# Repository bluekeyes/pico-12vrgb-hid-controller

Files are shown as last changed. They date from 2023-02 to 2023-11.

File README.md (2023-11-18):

# pico-12vrgb-hid-controller

A 4-channel 12V-G-R-B controller for RGB fans and LED strips using the Raspberry
Pi Pico and controlled via USB HID. Designed to be installed inside a PC case as
an alternative or addition to motherboard headers.

It implements the "Lighting and Illumination" (`0x59`) HID usage page, making
it fully compatible with the [Dynamic Lighting][] feature in Windows 11.

It also implements the "Sensors" (`0x20`) HID usage page (for a temperature
sensor) and a vendor (`0xFF00`) HID usage page for custom controls.

Note this does *not* support 3-pin addressable RGB LEDs, but uses the
semi-standard 4-pin 12V-G-R-B connector, where all devices connected to a
channel show the same color.

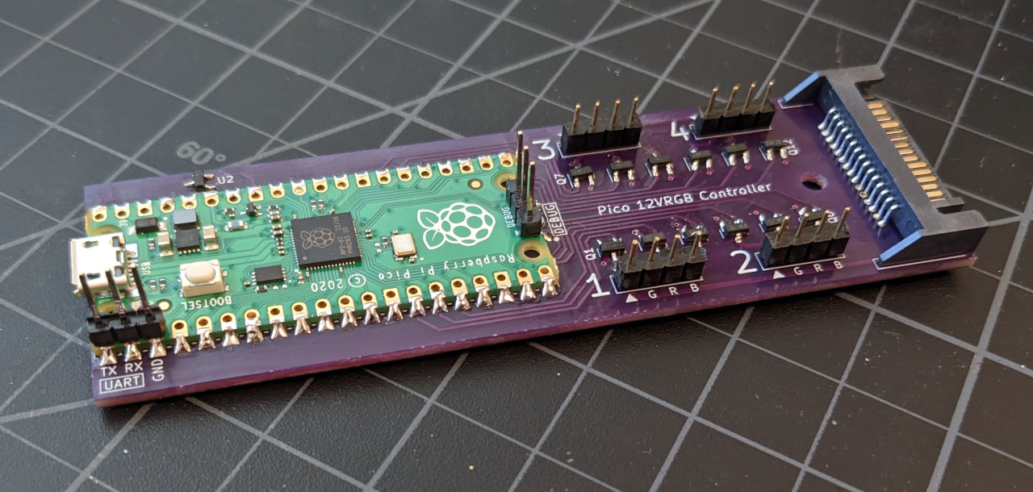
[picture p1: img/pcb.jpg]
The assembled pico-12vrgb-hid-controller PCB


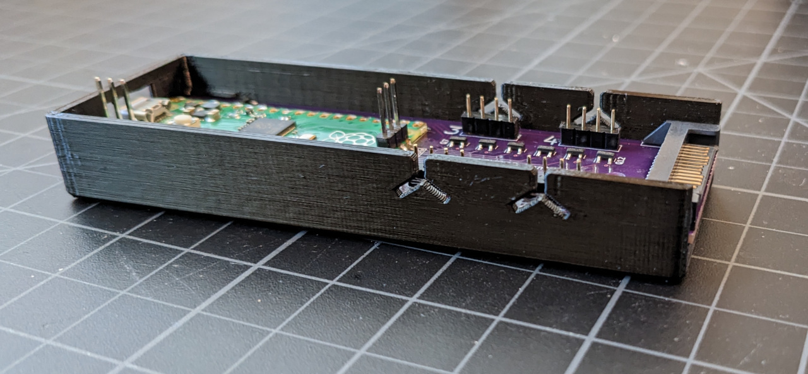
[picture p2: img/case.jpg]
The assembled PCB installed in the 3D-printed case


[Dynamic Lighting]: https://support.microsoft.com/en-us/windows/control-your-dynamic-lighting-devices-in-windows-8e8f22e3-e820-476c-8f9d-9ffc7b6ffcd2

## Animations

When running in autonomous mode, the controller implements configurable
animations. Use the CLI to set the parameters or save an animation as the
default for a channel.

### Breathe

Fades a single color on and off. The fade on time, on time, fade off time, and
off time are all configurable.

https://user-images.githubusercontent.com/1745813/233868169-5f5d1403-0b08-4b99-b51f-30fe5f666057.mp4

### Fade

Fades between up to 8 different colors. The fade time and hold time are
configurable.

https://user-images.githubusercontent.com/1745813/233868393-662b7a13-106e-483d-9052-4a47977f7780.mp4

## Project Structure

This project is split into three parts:

* `hw/` contains schematics and PCB files (KiCAD)
* `fw/` contains device firmware (C)
* `cli/` contains the command-line control program (Rust)

See each directory for more details.

## Limitations

The hardware is only tested on Windows 11, using both the Dynamic Lighting
feature and the included CLI. The CLI does not support other platforms yet. 

## License

MIT

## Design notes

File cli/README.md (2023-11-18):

# pico-12vrgb-ctrl

A program to control the USB device from the command line. See the help output
for details on the supported commands:

```
Usage: pico-12vrgb-ctrl.exe [OPTIONS] <COMMAND>

Commands:
  lamp-array       Control lights directly
  set-animation    Manage built-in animations
  reset            Reset the controller hardware
  get-temperature  Read the internal temperature sensor
  help             Print this message or the help of the given subcommand(s)

Options:
      --vendor-id <ID>   Override the USB vendor ID for the device
      --product-id <ID>  Override the USB product ID for the device
  -h, --help             Print help
  -V, --version          Print version
```

## Platform Support

The CLI is structured to support multiple platforms, but currently only
implements a Windows backend. Other backends might be added if there's a need
for them.

### Windows

On Windows, the CLI uses WinRT and Win32 APIs (via the [`windows`
crate][windows-rs]) to interact with the device. Partly due to API limitations
and partly for simplicity, the CLI sends reports in the exact binary format
expected by the device. This means it only works with the firmware from this
repository and that the CLI version and the firmware version must match.

The main reason to use Windows APIs directly instead of an abstraction library
like `hidapi` is that sensor devices are only accessible via the Win32 Sensors
API and are hidden from the normal HID APIs.

The CLI uses exact binary report formats because the
`Windows.Devices.HumanInterfaceDevice` API provides no way I could find to set
repeated report items by HID usage. I think this limitation does not exist in
the lower-level Win32 HID API, but the WinRT API is easier to use and has nicer
Rust bindings.

Currently, all parts of the `lamp-array` subcommand exit immediately. Similar
to sensors, once a HID device is detected as as a more specific subclass,
Windows hides it from the generic HID APIs. The `Windows.Devices.Lights` API
does not map one-to-one with the underlying HID messages and so isn't a direct
replacement. It also has limitations on when apps can use this API to control
the device (e.g. they must be in the foreground.)

The [Dynamic Lighting][] UI is a reasonable substitute for most of the
`lamp-array` subcommmands.

[windows-rs]: https://crates.io/crates/windows
[Dynamic Lighting]: https://support.microsoft.com/en-us/windows/control-your-dynamic-lighting-devices-in-windows-8e8f22e3-e820-476c-8f9d-9ffc7b6ffcd2

## Development

This is a standard Rust project that builds with `cargo`. There are no
requirements apart from a working Rust installation.

From this directory:

```
# compile the binary, output is in the `target/debug` directory
$ cargo build

# complie and run the binary, with subcommands and flags after the "--"
$ cargo run -- set-animation --help
```

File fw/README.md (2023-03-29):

# pico-12vrgb-controller

This directory contains a Pico SDK project for the controller firmware. The
Raspberry Pi Pico SDK and `cmake` are required.

## Building

```
export PICO_SDK_PATH=/path/to/pico-sdk-1.5.0
mkdir build
cd build
cmake ..
make
```

Edit `src/config.h` before building to modify device configuration.

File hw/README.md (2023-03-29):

# Hardware

This directory contains design files for the controller hardware:

* `pcb` - a KiCAD 7.x project with the schematic and PCB design
* `case` - OpenSCAD and STL files for a simple 3D printed case for the PCB

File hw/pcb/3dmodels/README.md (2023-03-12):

# 3D Models

This directory contains 3D models associated with KiCad footprints in this project:

* `moddiy_15pin_sata_right_angle_header.step` - created from datasheet and physical measurments
* `raspberry_pi_pico_r3.step` - original file available at https://www.raspberrypi.com/documentation/microcontrollers/raspberry-pi-pico.html, modified to have colors

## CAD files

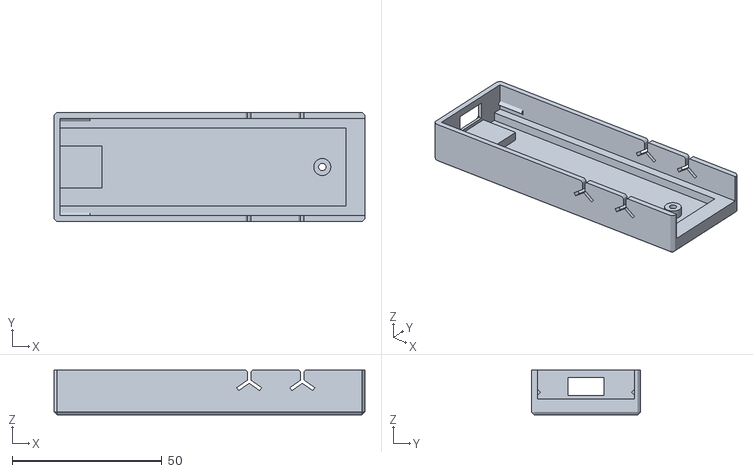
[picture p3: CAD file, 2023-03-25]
hw/case/case.stl
104.0 x 36.5 x 15.0

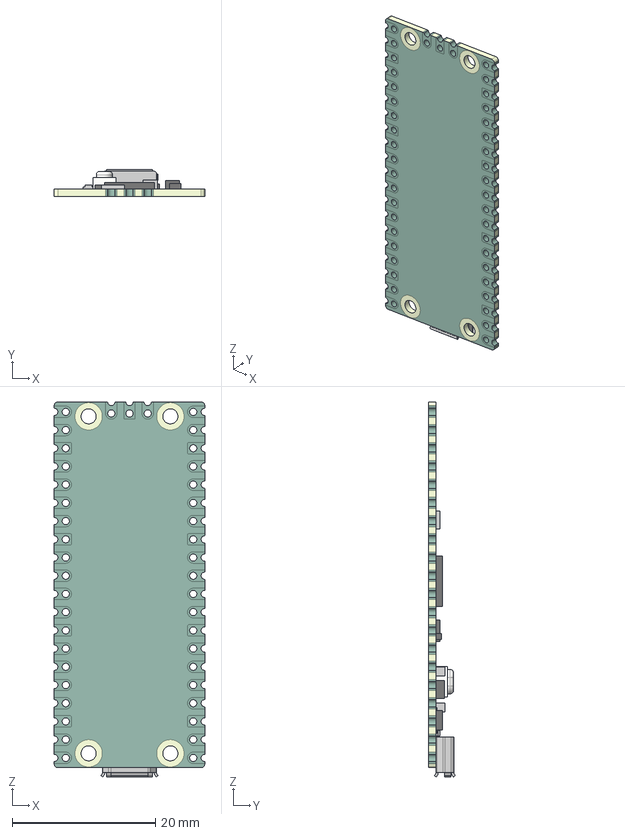
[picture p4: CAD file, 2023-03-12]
hw/pcb/3dmodels/raspberry_pi_pico_r3.step
21.0 x 3.73 x 52.3 mm
PICO_REF_BOARD.STEP
PICO_REF_USB.STEP
PICO_REF_SWITCH.STEP
PICO_REF_MICROCONTROLLER.STEP
PICO_REF_LED.STEP
PICO_REF_ONSEMI.STEP
PICO_BOURNS.STEP
PICO_MURATA.STEP x 2
PICO_RICHTEK.STEP
PICO_DIODES.STEP
PICO_AEL.STEP
PICO_WINBOND.STEP

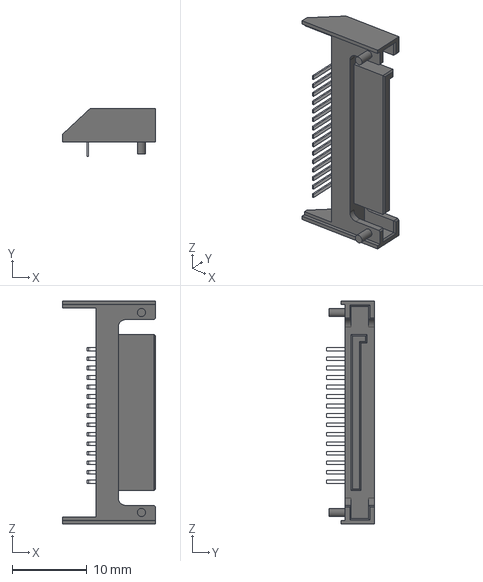
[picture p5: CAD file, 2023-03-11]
hw/pcb/3dmodels/moddiy_15pin_sata_right_angle_header.step
12.5 x 6.50 x 29.9 mm

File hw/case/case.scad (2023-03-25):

function in2mm(v) = 25.4*v;

$fa = 0.5;
$fs = 0.35;
eps = 1;

wall = 2;
standoff_wall = 1.6;

pcb_width = in2mm(1.25);
pcb_length = in2mm(4);
pcb_height = 1.6;

pcb_clearance = 0.4;
pin_clearance = 3;

rgb_offset_x = in2mm(0.825);
rgb_offset_y = in2mm(0.175);
rgb_spacing = in2mm(0.7);

rgb_cable_width = 5;
rgb_cable_height = 1.2;

usb_width = 12;
usb_height = 6;
usb_center_offset_z = 2.5;

case_width = 2*wall + 2*pcb_clearance + pcb_width;
case_length = wall + pcb_clearance + pcb_length;
case_floor = 2.4;
case_pcb_depth = 8;
case_height = case_floor + pin_clearance + pcb_height + case_pcb_depth;

screw_diameter = 2.5;
screw_length = 6;
screw_offset = in2mm(0.5625);

clip_size = 1;

assert(pcb_height + pin_clearance + case_floor >= screw_length, "screw is too long for the mounting hole");

module mirror_x() {
    children(); mirror([1, 0, 0]) children();
}

module mirror_y() {
    children(); mirror([0, 1, 0]) children();
}

module mirror_z() {
    children(); mirror([0, 0, 1]) children();
}

module rgb_cable_guide(h, angle=45) {
    translate([0, -eps/2, -h])
    union() {
        mirror_x()
        translate([rgb_cable_height/2, 0, 0])
        rotate([0, -angle, 0])
        translate([-rgb_cable_width, 0, 0])
        cube([rgb_cable_width, wall + eps, rgb_cable_height]);

        translate([-rgb_cable_height/2, 0, 0])
        cube([rgb_cable_height, wall + eps, h + eps]);

        mirror_x()
        translate([rgb_cable_height/2, (wall + eps)/2, h])
        rotate([180, 0, 90])
        chamfer_mask(rgb_cable_height/2, wall + eps);
    }
}

module chamfer_mask(s, length) {
    rotate([0, -90, 0])
    linear_extrude(length, center=true)
    polygon([
        [-eps, -eps], [s, -eps], [s, 0], [0, s], [-eps, s]
    ]);
}

module chamfer_outside_corner_mask(s) {
    polyhedron(
        points = [
            [0, 0, 0], [0, 0, s],
            [s, 0, s], [s, 0, 0],
            [0, s, s], [0, s, 0],
            [s, s, 0]
        ],
        faces = [
            // chamfer face
            [2, 4, 6],
            // side faces
            [2, 6, 3],
            [0, 1, 2, 3],
            [5, 4, 1, 0],
            [5, 6, 4],
            // top
            [1, 4, 2],
            // bottom
            [0, 3, 6, 5],
        ]
    );
}

module chamfer_inside_corner_mask(s) {
    polyhedron(
        points = [
            [eps, 0, 0], [0, eps, 0], [0, 0, eps],
            [0, 0, -s], [eps, 0, -s], [0, eps, -s],
            [-s, 0, 0], [-s, eps, 0], [-s, 0, eps],
            [0, -s, 0], [eps, -s, 0], [0, -s, eps],
        ],
        faces = [
            // chamfer face
            [3, 6, 9],
            // bottom side faces
            [3, 9, 10, 4],
            [10, 0, 4],
            [3, 5, 7, 6],
            [7, 5, 1],
            [1, 5, 4, 0],
            // top side faces
            [9, 6, 8, 11],
            [9, 11, 10],
            [10, 11, 2, 0],
            [0, 2, 1],
            [1, 2, 8, 7],
            [6, 7, 8],
            // top face
            [2, 11, 8],
            // bottom face
            [3, 4, 5],
        ]
    );
}

module case_shell() {
    chamfer = wall/2;

    difference() {
        // body
        translate([-case_length/2, -case_width/2, 0])
        cube([case_length, case_width, case_height]);

        // bottom length chamfers
        mirror_y()
        translate([0, -case_width/2, 0])
        chamfer_mask(chamfer, case_length);

        // bottom width chamfers
        mirror_x()
        translate([case_length/2, 0, 0])
        rotate([0, 0, 90])
        chamfer_mask(chamfer, case_width);

        // vertical corner chamfers
        mirror_x()
        mirror_y() {
            translate([-case_length/2, -case_width/2, 0]) {
                translate([0, 0, case_height/2])
                rotate([0, 90, 0])
                chamfer_mask(chamfer, case_height + eps);

                chamfer_outside_corner_mask(chamfer);
            }
        }

        // main cutout 
        translate([
            -case_length/2 + wall,
            -pcb_width/2 - pcb_clearance,
            case_floor
        ])
        cube([
            pcb_clearance + pcb_length + eps,
            2*pcb_clearance + pcb_width,
            case_height - case_floor + eps,
        ]);

        // usb cutout
        let (
            dz = case_floor + pin_clearance + pcb_height + usb_center_offset_z
        ) {
            translate([
                -(case_length + eps)/2,
                -usb_width/2,
                dz - usb_height/2,
            ])
            cube([wall + eps, usb_width, usb_height]);

            // chamfers
            translate([-case_length/2, 0, dz]) {
                mirror_z()
                translate([0, 0, usb_height/2])
                rotate([0, 0, -90])
                chamfer_mask(chamfer, usb_width);

                mirror_y()
                translate([0, -usb_width/2, 0])
                rotate([90, 0, 0])
                rotate([0, 0, -90])
                chamfer_mask(chamfer, usb_height);

                mirror_y()
                mirror_z()
                translate([0, -usb_width/2, -usb_height/2])
                rotate([0, -90, 0])
                chamfer_inside_corner_mask(chamfer);
            }
        }

        // rgb cable guides
        mirror_y() {
            for (i = [0, 1]) {
                translate([
                    case_length/2 - rgb_offset_x - i*rgb_spacing,
                    -case_width/2,
                    case_height,
                ])
                rgb_cable_guide(0.5 * case_pcb_depth, angle=35);
            }
        }
    }
}

module standoffs() {
    edge_width = in2mm(0.125);
    pico_length = 14;
    pico_width = 14;
    sata_length = in2mm(0.25);
    inner_w = pcb_width + 2*pcb_clearance;

    // edge supports
    mirror_y()
    translate([
        -case_length/2 + wall,
        (pcb_width/2 + pcb_clearance) - edge_width,
        0,
    ])
    cube([pcb_length + pcb_clearance, edge_width, pin_clearance]);

    // sata connector support
    translate([case_length/2 - sata_length, -inner_w/2, 0])
    cube([sata_length, inner_w, pin_clearance]);

    // pico support
    translate([-case_length/2 + wall, -pico_width/2, 0])
    cube([pico_length, pico_width, pin_clearance]);

    // screw standoff
    translate([case_length/2 - screw_offset, 0, 0])
    cylinder(d=screw_diameter + 2*standoff_wall, h=pin_clearance);
}

module clips(length) {
    dz = pcb_height - pcb_clearance;
    mirror_y()
    translate([
        0,
        pcb_width/2 + pcb_clearance,
        case_floor + pin_clearance + clip_size + dz,
    ])
    rotate([0, 90, 0])
    cylinder(r=clip_size, h=length, $fn=4);
}

module case() {
    difference() {
        union() {
            case_shell();
            translate([0, 0, case_floor]) standoffs();

            translate([-case_length/2 + wall, 0, 0])
            clips(10);
        }

        // screw hole
        translate([case_length/2 - screw_offset, 0, -eps/2])
        cylinder(d=screw_diameter, h=case_floor + pin_clearance + eps);
    }
}

case();

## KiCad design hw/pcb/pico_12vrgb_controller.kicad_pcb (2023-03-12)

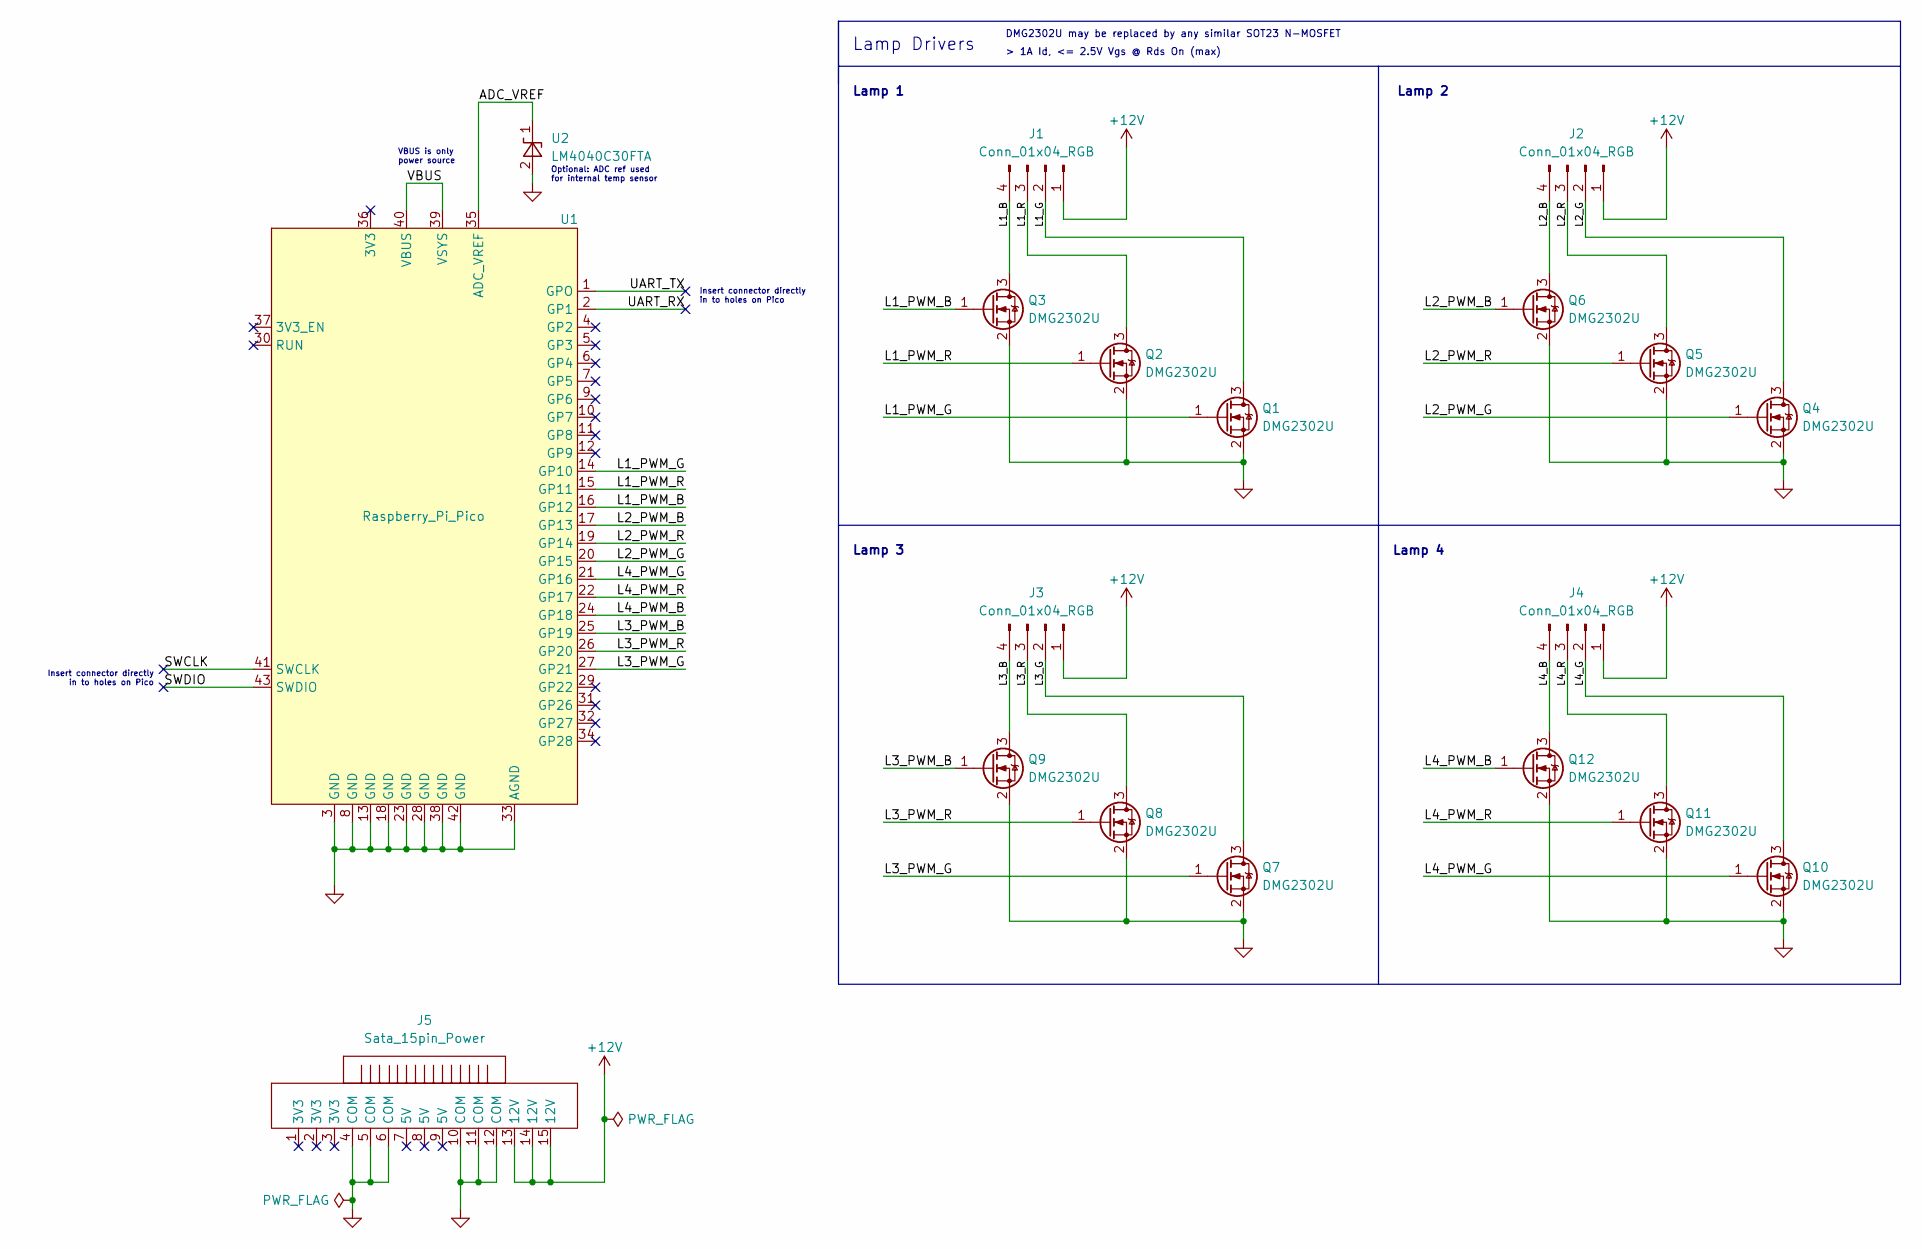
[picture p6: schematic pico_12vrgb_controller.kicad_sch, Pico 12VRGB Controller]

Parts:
J1, J2: Conn_01x04_RGB; PinHeader_12VGRB_Vertical_LeftText
J3, J4: Conn_01x04_RGB; PinHeader_12VGRB_Vertical_RightText
J5: Sata_15pin_Power; ModDIY_SATA_15pin_RightAngle_Header
Q1, Q2, Q3, Q4, Q5, Q6, Q7, Q8, Q9, Q10, Q11, Q12: DMG2302U; SOT-23
U1: Raspberry_Pi_Pico; RPi_Pico_SMD
U2: LM4040C30FTA; SOT-23

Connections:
+12V: J1.1, J2.1, J3.1, J4.1, J5.13 (12V), J5.14 (12V), J5.15 (12V)
/ADC_VREF: U1.35 (ADC_VREF), U2.1 (K)
/L1_B: J1.4, Q3.3 (D)
/L1_G: J1.2, Q1.3 (D)
/L1_PWM_B: Q3.1 (G), U1.16 (GP12)
/L1_PWM_G: Q1.1 (G), U1.14 (GP10)
/L1_PWM_R: Q2.1 (G), U1.15 (GP11)
/L1_R: J1.3, Q2.3 (D)
/L2_B: J2.4, Q6.3 (D)
/L2_G: J2.2, Q4.3 (D)
/L2_PWM_B: Q6.1 (G), U1.17 (GP13)
/L2_PWM_G: Q4.1 (G), U1.20 (GP15)
/L2_PWM_R: Q5.1 (G), U1.19 (GP14)
/L2_R: J2.3, Q5.3 (D)
/L3_B: J3.4, Q9.3 (D)
/L3_G: J3.2, Q7.3 (D)
/L3_PWM_B: Q9.1 (G), U1.25 (GP19)
/L3_PWM_G: Q7.1 (G), U1.27 (GP21)
/L3_PWM_R: Q8.1 (G), U1.26 (GP20)
/L3_R: J3.3, Q8.3 (D)
/L4_B: J4.4, Q12.3 (D)
/L4_G: J4.2, Q10.3 (D)
/L4_PWM_B: Q12.1 (G), U1.24 (GP18)
/L4_PWM_G: Q10.1 (G), U1.21 (GP16)
/L4_PWM_R: Q11.1 (G), U1.22 (GP17)
/L4_R: J4.3, Q11.3 (D)
/SWCLK: U1.41 (SWCLK)
/SWDIO: U1.43 (SWDIO)
/UART_RX: U1.2 (GP1)
/UART_TX: U1.1 (GPO)
/VBUS: U1.39 (VSYS), U1.40 (VBUS)
GND: J5.4 (COM), J5.5 (COM), J5.6 (COM), J5.10 (COM), J5.11 (COM), J5.12 (COM), Q1.2 (S), Q2.2 (S), Q3.2 (S), Q4.2 (S), Q5.2 (S), Q6.2 (S), Q7.2 (S), Q8.2 (S), Q9.2 (S), Q10.2 (S), Q11.2 (S), Q12.2 (S), U1.3 (GND), U1.8 (GND), U1.13 (GND), U1.18 (GND), U1.23 (GND), U1.28 (GND), U1.33 (AGND), U1.38 (GND), U1.42 (GND), U2.2 (A)

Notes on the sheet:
Lamp 2
Lamp Drivers
> 1A Id, <= 2.5V Vgs @ Rds On (max)
Insert connector directly in to holes on Pico
DMG2302U may be replaced by any similar SOT23 N-MOSFET
Optional: ADC ref used for internal temp sensor
Lamp 4
Lamp 1
VBUS is only power source
Lamp 3

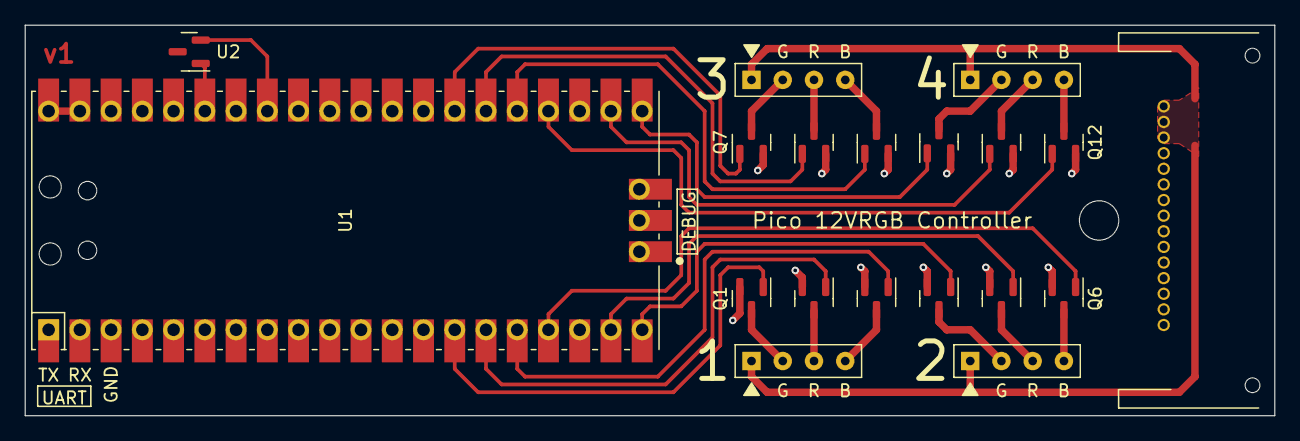
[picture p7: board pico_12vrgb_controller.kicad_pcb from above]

Board: 2 copper layers, 101.6 x 31.8 mm, 19 parts (0 on the bottom side), 28 nets.

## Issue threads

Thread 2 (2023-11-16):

Fix compatibility with Windows Dynamic Lighting

bluekeyes, 2023-11-16:
Now that Dynamic Lighting is available in Window 11, it turns out my device isn't actually compatible. As discussed a bit [in the README for the `cli` package](https://github.com/bluekeyes/pico-12vrgb-hid-controller/tree/main/cli#windows), when I tried to test this using the Windows APIs previously, I ran in to a hang that I couldn't solve. Unsurprisingly, whatever causes that problem also prevents Dynamic Lighting from working, since it presumably uses the same underlying APIs.

Since I last tried debugging this, Microsoft published https://github.com/microsoft/RP2040MacropadHidSample, which is also an RP2040-based implementation. The `LampArray` APIs correctly discover a device running this sample code without hanging, which proves that the issue is with my code and not with Windows. I now think there's something wrong with my HID descriptor that causes the Windows APIs to hang.

bluekeyes, 2023-11-17:
Updating the HID descriptor fixed the hang and the device now appears in the Dynamic Lighting settings page. Enabling and disabling autonomous mode works, but it doesn't actually respond to color changes. Still have some more debugging to do here.

Closed 2023-11-18.

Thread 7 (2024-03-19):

Find an alternate way to access HID interfaces from CLI

bluekeyes, 2024-03-19:
Once Windows detects a HID device as implementing a more specific API in the WinRT set, it seems to hide it from the generic WinRT HID API. While you can often still list the device, I couldn't actually open it or send messages.

This is mostly an issue for the `lamp-array` subcommand, which is a direct binding to the Lighting and Illuminate HID API.

I haven't tried yet, but I suspect the lower-level win32 HID API might allow access to this device, even if the higher-level APIs do not: https://learn.microsoft.com/en-us/windows/win32/api/_hid/

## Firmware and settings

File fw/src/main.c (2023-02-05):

#include "hardware/sync.h"
#include "pico/stdlib.h"
#include "tusb.h"

#include "color/color.h"
#include "controller/animations/fade.h"
#include "controller/controller.h"
#include "controller/persist.h"
#include "controller/sensor.h"
#include "device/lamp.h"
#include "device/temperature.h"
#include "hid/vendor/report.h"

controller_t ctrl;
sensor_controller_t sensectrl;

bool is_suspended = false;

int main()
{
    stdio_init_all();

    lamp_init();
    temperature_init();

    ctrl_init(&ctrl);
    ctrl_sensor_init(&sensectrl);
    ctrl_persist_init();

    tusb_init();

    // Set default animations for all lamps
    for (uint8_t id = 0; id <= MAX_LAMP_ID; id++) {
        struct Vendor12VRGBAnimationReport *report = ctrl_persist_find_report(id);
        if (report != NULL) {
            ctrl_set_animation_from_report(&ctrl, report);
        }
    }

    while (true) {
        tud_task();

        // If suspended, block waiting for any event. On any wake-up (real or
        // spurius), restart the loopo and execute the USB task, because that's
        // what will clear the suspended flag. Skip any other tasks while suspended.
        if (is_suspended) {
            __wfe();
        } else {
            ctrl_task(&ctrl);
            ctrl_sensor_task(&sensectrl);
        }
    }

    return 0;
}

void suspend()
{
    if (!is_suspended) {
        ctrl_suspend(&ctrl);
        is_suspended = true;
    }
}

void resume()
{
    if (is_suspended) {
        ctrl_resume(&ctrl);
        is_suspended = false;
    }
}

void tud_suspend_cb(bool remote_wakeup_en)
{
    suspend();
}

void tud_resume_cb()
{
    resume();
}

void tud_mount_cb(void)
{
    // For some reason (possibly because of the sensor usage), Windows is not
    // resuming the device when exiting sleep, but instead doing a bus reset,
    // which appears to tinyUSB as a mount event. Treat this as a normal resume
    // because we still get a suspend event on entering sleep.
    resume();
}

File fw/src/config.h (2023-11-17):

#ifndef CONFIG_H_
#define CONFIG_H_

#include "hid/lights/usage.h"

// The device version as 0xJJMN, where JJ is the major version, M is the minor
// version and N is the patch version.
#define CFG_RGB_DEVICE_VERSION 0x0010

// The USB vendor and product IDs for the device.
//
// See https://pid.codes
#define CFG_RGB_USB_VID   0x1209
#define CFG_RGB_USB_PID   0xB210

// The dimensions of the bounding box that contains all lights
//
// Range: [0, 2^31-1]
// Units: Micrometers
#define CFG_RGB_BOUNDING_BOX_WIDTH  0
#define CFG_RGB_BOUNDING_BOX_HEIGHT 0
#define CFG_RGB_BOUNDING_BOX_DEPTH  0

// Lamp positions as (X, Y, Z) tuples relative to the bounding box origin. The
// number of entries must equal LAMP_COUNT (device/specs.h).
//
// Units: Micrometers
#define CFG_RGB_LAMP_POSITIONS \
    {0, 0, 0}, \
    {0, 0, 0}, \
    {0, 0, 0}, \
    {0, 0, 0},

// Lamp purpose flags. The number of entries must equal LAMP_COUNT
// (device/specs.h). The following flags are allowed, see Section 25.3.1 in the
// HID Usage Table for details:
//
//     LAMP_PURPOSE_CONTROL        0x01
//     LAMP_PURPOSE_ACCENT         0x02
//     LAMP_PURPOSE_BRANDING       0x04
//     LAMP_PURPOSE_STATUS         0x08
//     LAMP_PURPOSE_ILLUMINATION   0x10
//     LAMP_PURPOSE_PRESENTATION   0x20
//
#define CFG_RGB_LAMP_PURPOSES \
    LAMP_PURPOSE_ACCENT, \
    LAMP_PURPOSE_ACCENT, \
    LAMP_PURPOSE_ACCENT, \
    LAMP_PURPOSE_ACCENT,

// Map lamp RGB channels to GPIOs as (R, G, B) tuples. The number of entries
// must equal LAMP_COUNT (device/specs.h). Each GPIO in the mapping must
// connect to a unique PWM channel. For example, you may not use both GPIO 0
// and GPIO 16 because they are both connected to PWM channel 0A.
//
// The PCB routes these GPIOs so they appear on headers in G-R-B order. You can
// change this in software by swapping the positions for a given lamp.  Other
// changes to this options will require hardware changes.
#define CFG_RGB_LAMP_GPIO_MAPPING \
    {11, 10, 12}, \
    {14, 15, 13}, \
    {20, 21, 19}, \
    {17, 16, 18},

// Set the divider for the PWM clock. The PWM counters wrap at the full 16-bit
// value, so with a 125 MHz system clock, the default value gives a PWM
// frequency of ~250 Hz.
#define CFG_RGB_PWM_CLOCK_DIVIDER 7.625f

// The minimum update interval. This is the minimum amount of time a host must
// wait between sending complete lamp update reports. Because this device does
// nothing else, this defaults to the maximum update latency as determined by
// the PWM period.
//
// Range: [0, 2^31-1]
// Units: Microseconds
#define CFG_RGB_MINIMUM_UPDATE_INTERVAL 4000

// The maximum latency between requesting a lamp update and the change being
// visible. Assumed to be the constant for all lamps. This is primarly
// determined by the PWM period: an update at the start of a cycle will not be
// visible until the start of the next cycle.
//
// Range: [0, 2^31-1]
// Units: Microseconds
#define CFG_RGB_LAMP_UPDATE_LATENCY 4000

// The built-in animation framerate.
//
// Range: [1, PWM frequency]
// Units: Hz
#define CFG_RGB_ANIMATION_FRAME_RATE 120

// The number of samples of the internal sensor to average for each
// temperature reading.
#define CFG_RGB_TEMP_SENSOR_SAMPLES 3

// The actual voltage of the ADC reference voltage used for the temperature
// sensor. This will be the value of the external reference or the measured
// value of the particular Pi Pico power supply.
//
// Range: [1, 3.3]
// Units: Volts
#define CFG_RGB_TEMP_SENSOR_REF_VOLTAGE 2.99f

// A fixed value to adjust measured temperatures by to account for differences
// between RP2040 diodes or other factors.
//
// Units: Degrees Celsius
#define CFG_RGB_TEMP_SENSOR_ADJUST -5.0f

#endif

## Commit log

2022-12-31 Add tusb_config.h to configure TinyUSB
    I've reduced this to only the properties that I believe are required, as
    the example file contains a lot of stuff that is only needed when
    supporting multiple target boards.
2023-01-03 Add descriptors for Lighting HID reports
    I think this is correct, but the spec leaves a lot of the field sizing
    up to implementations and I've made some guesses at how things are laid
    out, particularly for the LampMultiUpdateReport.
    [config.h]
2023-01-03 Revert back to "standard" brace layout
    The C convention (at least in the code I've looked at recently) seems to
    put function braces on a new line.
    [main.c]
2023-01-04 Simplify and generalize HID report descriptor
    The number of update slots in the LampMultiUpdateReport is controlled by
    a configuration macro and a bunch of other duplication was reduced
    through macros.
2023-01-05 Move device state to new controller_t struct
    This will also define all the logic for the device, so that it's not
    implemented directly in the USB callbacks.
2023-01-06 Add functions for controlling lamps
    Configure the appropriate pins and PWM channels, then add a function for
    updating lamp values and call it from the USB handler.
2023-01-06 Fix PWM initialization
    Operator precedence got me, equality comes before bitwise AND.
    [rgb.c]
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2023-01-09 Add generic animation support, starting with fades
    Define new animations with a data struct and a frame function. The
    controller managages animation playback, generating new frames as
    needed.
    I still need to figure out how assigning animations to channels should
    work and add the USB functionality for configuring them.
2023-01-09 Remove rgb.h, refactor config references
    Move most of the functionality in rgb.h to lamp.h, which better reflects
    what it actually does. As part of this, create device/specs.h as the One
    True Way to reference configuration. This includes the existing config.h
    file and also defines properties that aren't actually configurable, like
    the lamp count.
2023-01-11 Attach animation to specific lamps / channels
    All animations run in lockstep, so "multichannel" animations are
    implemented by running N individual animations that have coordinated
    logic based on the frame count.
2023-01-16 Add OUT interrupt endpoint to USB descriptor
    The majority of the device function happens via output reports and since
    these might be part of animations, it seems best to send them over a
    dedicated lower-latency pipe.
    Also clean up some remaining TODOs in the USB code, verifying that all
    the flags passed to things are correct, or at least documented.
    [config.h]
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2023-01-16 Enable UART output, add persist debug method
    I'm not sure how else to verify the flash features, so enable print
    debugging via UART. I have a USB to serial adapater, but don't have
    anything that can interface with the 3-wire debug port, so this is
    easiest.
2023-01-17 Revert to using control endpoint for output
    Adding the interrupt out endpoint broke discovery of lighting and
    illumination device via hidapi in Windows, but it still appeared in
    Device Manager, so I'm not sure what's wrong. Go back to the
    configuration that works for now.
2023-01-22 Add initial hardware design
    I think the schematic is mostly complete, but the PCB needs work.
    [pico_12vrgb_controller.kicad_pcb, pico_12vrgb_controller.kicad_sch]
2023-01-22 Disable lamps on USB host suspend
    In the future, I might add support for a special animation or something
    while suspended, but I suspect that would also require powering the Pico
    off of the +5V input from the PSU instead of just using VBUS from the
    USB connection. Right now, I'm not planning to support that to simplify
    the PCB (since USB is required for everything else anyway.)
2023-01-23 Send keepalive reports to block USB suspend
    Windows 11 seems to selectively suspend USB HID devices that are idle
    for 5-10s. We want to get a suspend event only when the system goes to
    sleep, so send perioding messages to make Windows think we're doing
    something.
    Theoretically you can disable this behavior in the OS, but I couldn't
    get it to work and having to specially configure something that is
    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
2023-01-24 Add custom model and footprint for SATA connector
    I might need to change this, because the ModDIY listing shows two
    different connectors in the pictures, but only has one data sheet
    picture. Hopefully both connectors work with the same footprint.
    [moddiy_15pin_sata_right_angle_header.step, pico_12vrgb_controller.kicad_pcb, pico_12vrgb_controller.kicad_sch]
2023-01-27 Remove keepalive messages
    While this solves the initial problem of selective suspension, it
    doesn't seem to keep working after resuming from a global sleep. I
    suspect that with nothing reading the messages something gets messed up
    on either the host or the device, but I wasn't able to figure out
    exactly what goes wrong.
    [config.h]
2023-01-29 Add temperature sensor to HID report
    The primary purpose for this usage is to trick Windows into leaving the
    device in the active state until there is a global suspend as part of
    going to sleep. By default, Windows selectively suspends the device when
    the bus is idle for a few seconds. I believe this is because nothing
    uses the lighting or vendor pages by default, so there are no open
    connections to the device. To avoid a special driver or service that's
    always running, declare a usage that Windows opens by default [1].
    Temperature is a good choice because the RP2040 has an internal sensor,
    so I can actually provide data with low effort instead of lying about
    usages and having an approximat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
2023-01-29 Add ADC reference to schematic
    Planning to use the internal temperature sensor and given the small
    voltages involved, adding a reference sounds like a good idea.
    Also changes the UART header to be 4 pins, which seems more conventional
    even though the power pin will be disconnected.
    [pico_12vrgb_controller.kicad_pcb, pico_12vrgb_controller.kicad_sch]
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2023-01-30 Add PCB board edge and group plane
    Also arrange components in one layout that might work, configure the
    board properties for OSH Park, and fix alignment and pad sizes in the
    SATA connector footprint.
    [pico_12vrgb_controller.kicad_pcb]
2023-01-30 Start routing PCB, change header orientation
    The RGB half is mostly complete, although I might shift things around to
    save a bit of space. Still need to connect things up to the Pico.
    [pico_12vrgb_controller.kicad_pcb, pico_12vrgb_controller.kicad_sch]
2023-01-31 Finish PCB routing
    Reduce the size of the PCB to 5 square inches, although I could probably
    get it a bit smaller. Update the RGB header footprints with the correct
    pin sizes and nice labels. Finally, reassign PWM pins to enable cleaner
    routing.
    There's a bunch of DRC failures because I drew a shape over some traces
    instead of using a fill zone. I'll have to try this again and see if I
    can get the fill zone to do what I want.
    [pico_12vrgb_controller.kicad_pcb, pico_12vrgb_controller.kicad_sch]
2023-02-01 Fix 12V fill, minor PCB layout tweaks
    Clean up silkscreen, fix remaining DRC errors, expand pads on RGB header
    footprints, make the board slightly shorter on the USB end.
    [pico_12vrgb_controller.kicad_pcb, pico_12vrgb_controller.kicad_sch]
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2023-02-05 Fix resume behavior
    For some reason, possibly because of the sensor usage or maybe due to a
    tinyUSB bug, we don't get the resume callback when Windows wakes from
    sleep. Instead, it looks like we get a bus reset, which triggers the
    mount callback. Treat this as equivalent to the resume event. Because
    the device is bus-powered and internal, we don't really care about mount
    and unmount otherwise.
    Now that suspending and resuming works, block on events while suspended
    to minimize power usage.
    [main.c]
2023-02-05 Update lighting reports to better match spec
    I found an example descriptor in the original proposal for this page
    that indicates many of these reports should be feature reports, not
    input/output reports and also pointed out some places where I got the
    field sizes wrong.
    I'm not sure if these are actually critical, but Windows is refusing to
    open my device, and one theory is that something is wrong with my
    descriptors. At least in the sensor usage, Windows wouldn't recognize
    the device until the descriptor had certain fields.
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2023-02-12 Test and fix temperature sensor
    Using the Windows Sensor API confirmed this is working with minor
    tweaks, mostly fixing the enum values. Also remove "temp" from all the
    function and field names since this device only has one sensor.
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2023-02-21 Implement the reset command for Windows
    Use the WinRT APIs for now, since they're easier. For the LampArray
    commands, this will mean breaking abstraction and generating report
    data directly due to API limitations. But the CLI is meant for a single
    device and the end goal is to use the Lights API anyway.
2023-02-21 Fix warnings in unix device backend
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2023-02-23 Implement lamp array update commands
    Assume the binary format used by the pico-12vrgb-controller firmware for
    now. This should eventually use the Windows.Devices.Lights API, if the
    hang when opening devices is ever fixed (or I figure out what's wrong.)
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2023-02-26 Improve temp sensor usage on Windows
    Only initialize COM once, load and save the temperature sensor when
    creating the Device struct, and make sure the sensor we load is actually
    associated with the correct USB device.
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2023-03-05 Upgrade to KiCAD 7.0, add mounting hole to PCB
    [pico_12vrgb_controller.kicad_pcb, pico_12vrgb_controller.kicad_sch]
2023-03-05 Always accept sRGB values, linearize on device
    This makes the vendor interface more consistent with the Lighting and
    Illumination interface and avoids possible issues from lack of bit-depth
    when linearizing in 8-bit values.
2023-03-05 Add missing silkscreen markings
    Change debug label, add transistor markings, add version number.
    [pico_12vrgb_controller.kicad_pcb, pico_12vrgb_controller.kicad_sch]
2023-03-11 Update SATA footprint based on physical part
    Update minor dimensions in the 3D model, fix solder mask covering the
    holes in the footprint, and add the repository URL to the board.
    [moddiy_15pin_sata_right_angle_header.step, pico_12vrgb_controller.kicad_pcb]
2023-03-11 Improve pad connections to filled zones
    Use oval pads to get 90 degree connections, instead of circles, which
    seem to default to 45 degree connections. Also prefer oval pads for
    ground connections in the Pi Pico footprint.
    [pico_12vrgb_controller.kicad_pcb]
2023-03-11 Add plotted gerber files for the PCB
    [pico_12vrgb_controller-B_Cu.gbr, pico_12vrgb_controller-B_Mask.gbr, pico_12vrgb_controller-B_Paste.gbr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]
2023-03-11 Make PCB exactly 4" x 1.25"
    It was 0.025" shorter, which was silly. Make it a bit longer, move the
    SATA connector to the same relative position, and change the mounting
    hole to be a known distance from the board edge (0.5625")
    [pico_12vrgb_controller-B_Cu.gbr, pico_12vrgb_controller-B_Mask.gbr, pico_12vrgb_controller-B_Paste.gbr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]
2023-03-12 Add 3D model for Pi Pico footprint
    Colors are kind of messed up, possibly due to limits in the STEP file
    format or maybe because of issues with the Fusion 360 export. In either
    case, it's better than nothing.
    [pico_12vrgb_controller.kicad_pcb, raspberry_pi_pico_r3.step]
2023-03-13 Add case model
    This is mostly to insulate against the PC case and to help manage the
    RGB cables. Some foam mounting tape would probably work just as well if
    you don't want to mess with 3D printing.
    [case.scad, case.stl]
2023-03-25 Add chamfers to case
    Makes the case look a bit nicer, but doesn't impact function. Also
    confirm the dimensions of the screw hole.
    [case.scad, case.stl]
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2023-04-23 Fix VID/PID in test.py
2023-11-17 Fix lighting HID descriptor for Windows (#3)
    The Windows 11 implementation of the Lighting & Illumination page
    apparently requires that devices report a descriptor that exactly
    matches the example given in the original HUTRR84 proposal. When given a
    descriptor that does not match this example, the Windows APIs just hang,
    which is not very helpful for debugging.
    While I think my implementation was largely correct given what the HID
    specs say, here's what I had to change:
    * Always use feature reports, do not mix in output reports
    * Use 16 bits for LampID usages
    * Use 8 bits for LampUpdateFlags usages
    * Fix the maximum value of the AutonomousMode usage
    * Mark the lamp ID usage of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
    [config.h]
2023-11-18 Enable additional compiler errors
    Add -Wextra and -Wconversion, then fix resulting errors. I was most
    interested in implicit conversions as a result of changing the lamp ID
    type in the HID reports.
    [lamp.c]
2023-11-18 Temporarily disable lamp-array CLI functions
    Now that the device correctly reports as a HID LampArray, Windows hides
    it from the generic HID interface. Since the LampArray interface
    operates at a higher-level, it's not a direct replacement.
    I think I'll have to drop down to the Win32 HID/USB APIs if I want this
    to work. For now, just disable these commands since trying to load the
    HID device returns an error and breaks everything else.
    Most of this functionality is accessible through the Dynamic Lighting
    settings page anyway.
